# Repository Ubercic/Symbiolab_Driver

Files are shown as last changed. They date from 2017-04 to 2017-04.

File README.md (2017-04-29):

# Symbiolab Driver

## Overwiev 

Symbiolab driver was developed by institute IRNAS Rače for symbiolab biolaboratory. Its goal is to be used in as much as possible DIY laboratory equipment created for symbiolab's professional use in their research. A full list of planned DIY equipment can be found [here](https://github.com/symbiolab/bio-labware/blob/master/010_general_preparation.md). To achieve the most diverse use for the driver, we decidet to use a modular design, the most common components(display, encoder..) will be included in the driver, where as the design specific components(relay, ESC) are to be on a separate module.

## Table of contents

* Overwiev
* Table of contents
* Design specification
* Power supply config
* Board layout
* Pinout definition
* Testing
* Schemetics
* Featured installments

## Design specification

* [Nodemcu](http://nodemcu.com/index_en.html)
* Incremental encoder
* [I2C OLED display](https://www.adafruit.com/product/326)
* Motor driver [DRV8825](https://www.pololu.com/product/2133)
* Analog in pins for sensor readings
* 12V power supply
* mount screws

## Power supply config

Most of the desired elements controled with the driver work on 12 volts, to bring down the voltage to the required 5V in the Vin pin for the nodemcu we use a TLV1117 voltege regulator. Avidional voltage ripple tantal capacitors are wired before and after the regulator. to switch the nodemcu on and off, we added a power switch on the 12V line before the TLV1117. The nodemcu voltage level is 3V, but it takes 5V input.

## Board layout 

The PCB is designed to be montued as a faceplate on the lab equippment. Therefore most of the components are on the back ob the board. On the front there are the OLED display and incremental encoder, for the user control. All of the nodemcu pins are arranged in a raspberry pinout, this enables the use of raspberry shields.
The only analog pin on the nodemcu is separate with the 3v3 and GND pins next to it.

## Pinout definiton

Pionut definition

## Testing

## Schematics

The schematic and PCB design were crated with the free CAD software KiCAD.

## Featured installments

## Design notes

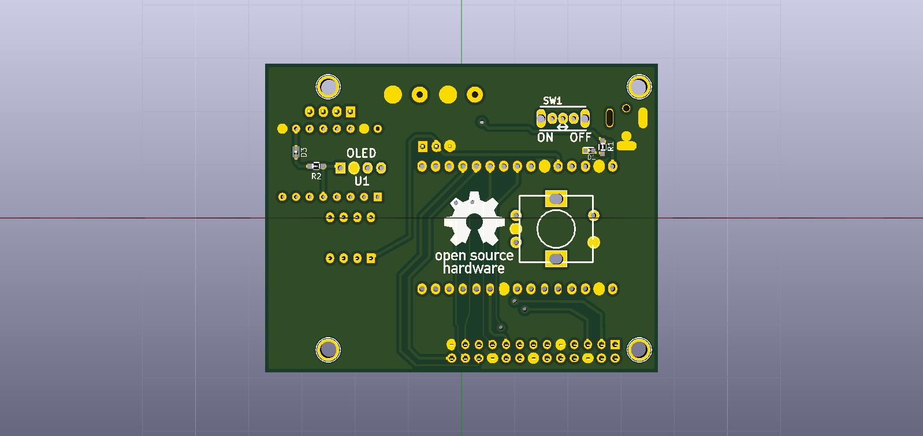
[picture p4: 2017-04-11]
KiCAD/IRNAS_Biolab_driver/Gerbers/IRNAS_BIOLAB_DRIVER_FRONT.jpg

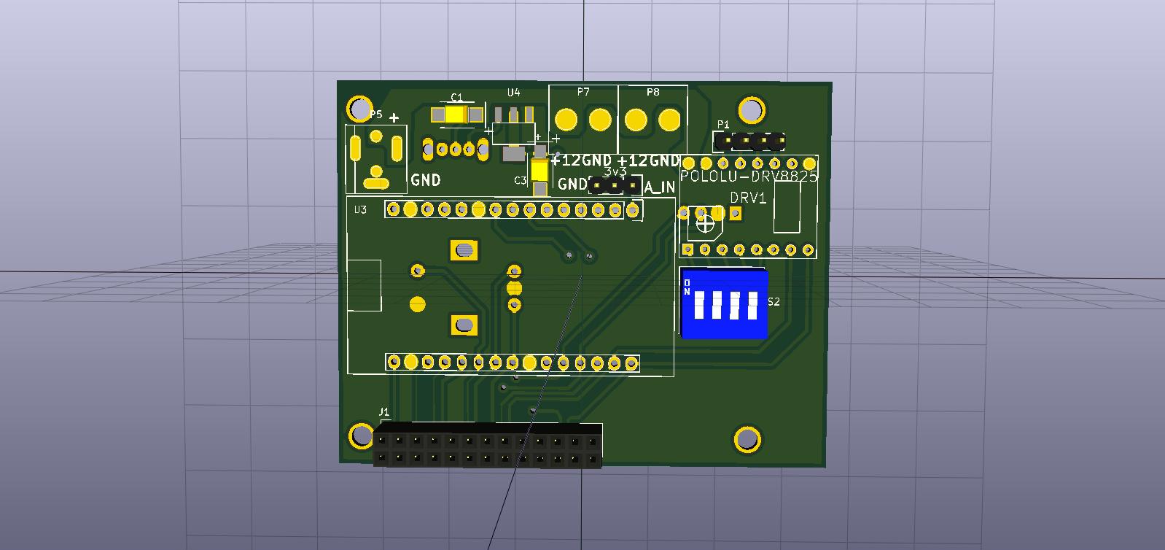
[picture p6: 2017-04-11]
KiCAD/IRNAS_Biolab_driver/Gerbers/IRNAS_BIOLAB_DRIVER_BACK.jpg

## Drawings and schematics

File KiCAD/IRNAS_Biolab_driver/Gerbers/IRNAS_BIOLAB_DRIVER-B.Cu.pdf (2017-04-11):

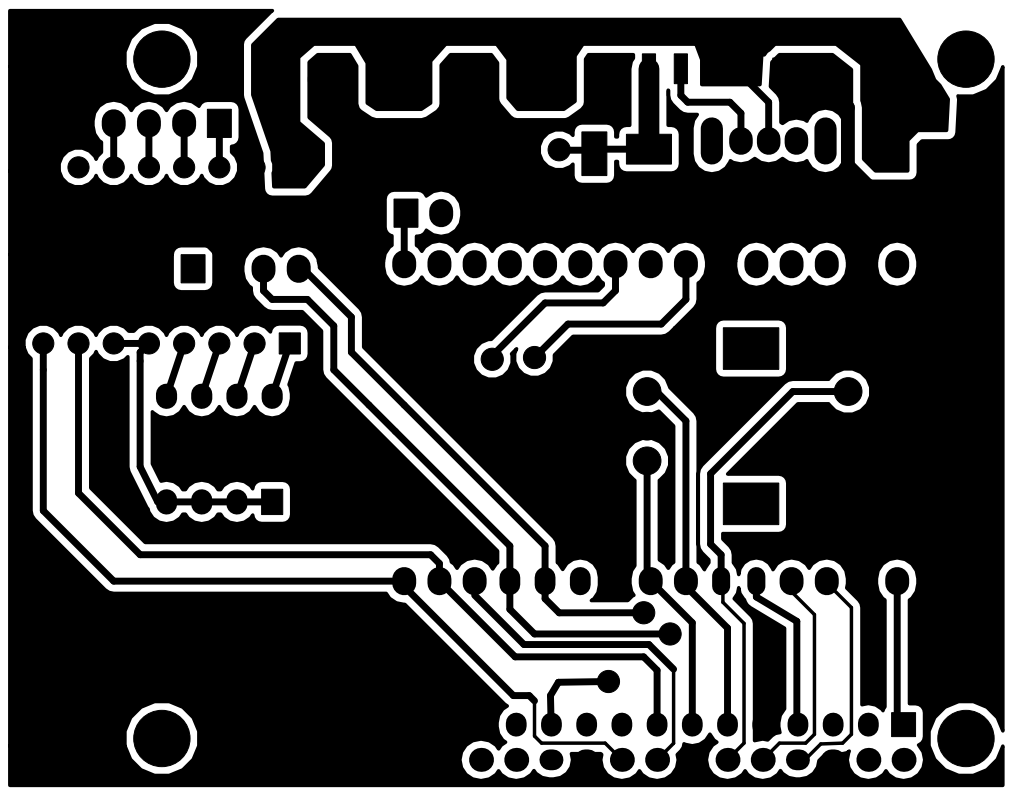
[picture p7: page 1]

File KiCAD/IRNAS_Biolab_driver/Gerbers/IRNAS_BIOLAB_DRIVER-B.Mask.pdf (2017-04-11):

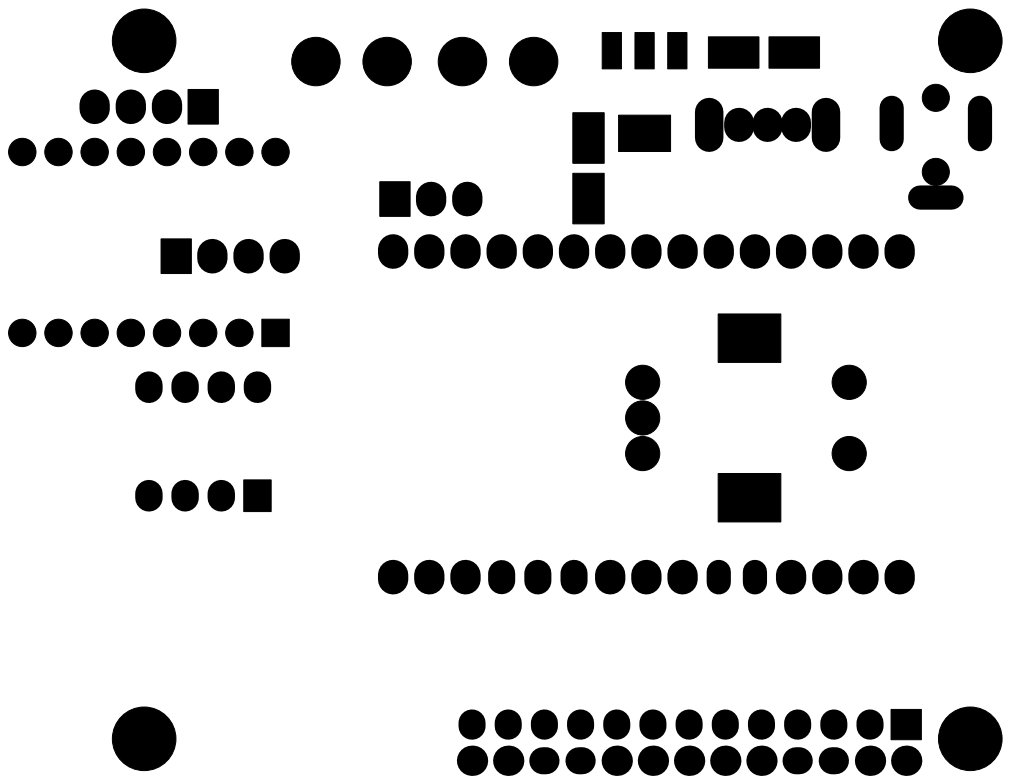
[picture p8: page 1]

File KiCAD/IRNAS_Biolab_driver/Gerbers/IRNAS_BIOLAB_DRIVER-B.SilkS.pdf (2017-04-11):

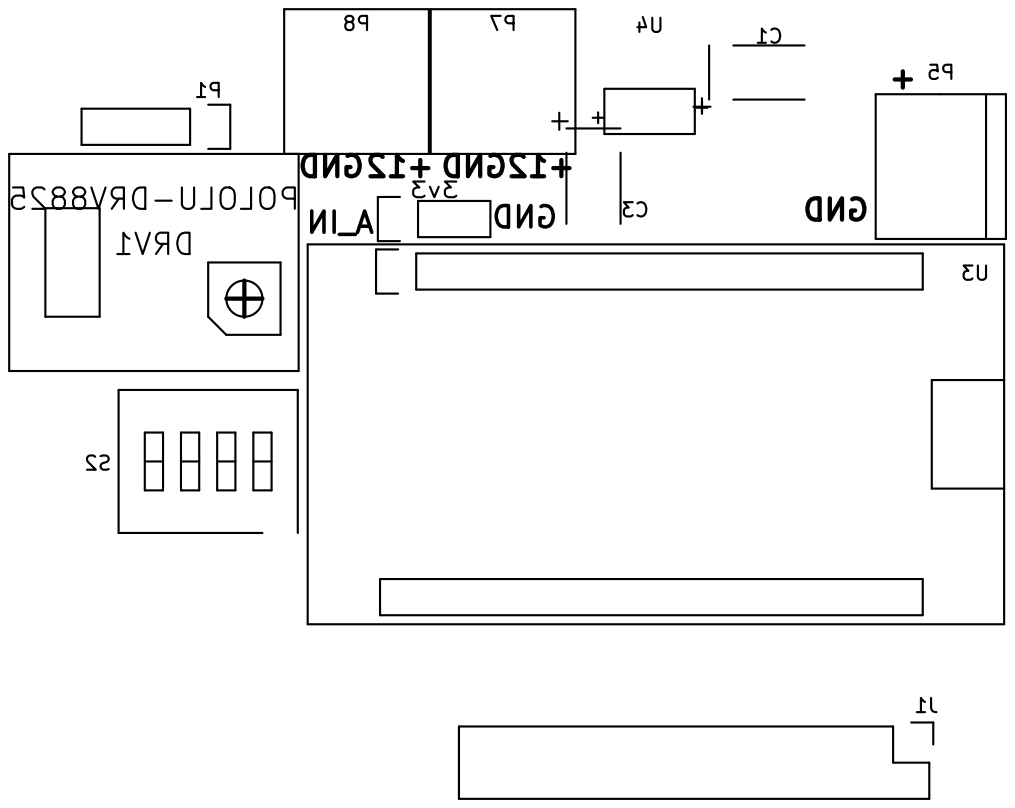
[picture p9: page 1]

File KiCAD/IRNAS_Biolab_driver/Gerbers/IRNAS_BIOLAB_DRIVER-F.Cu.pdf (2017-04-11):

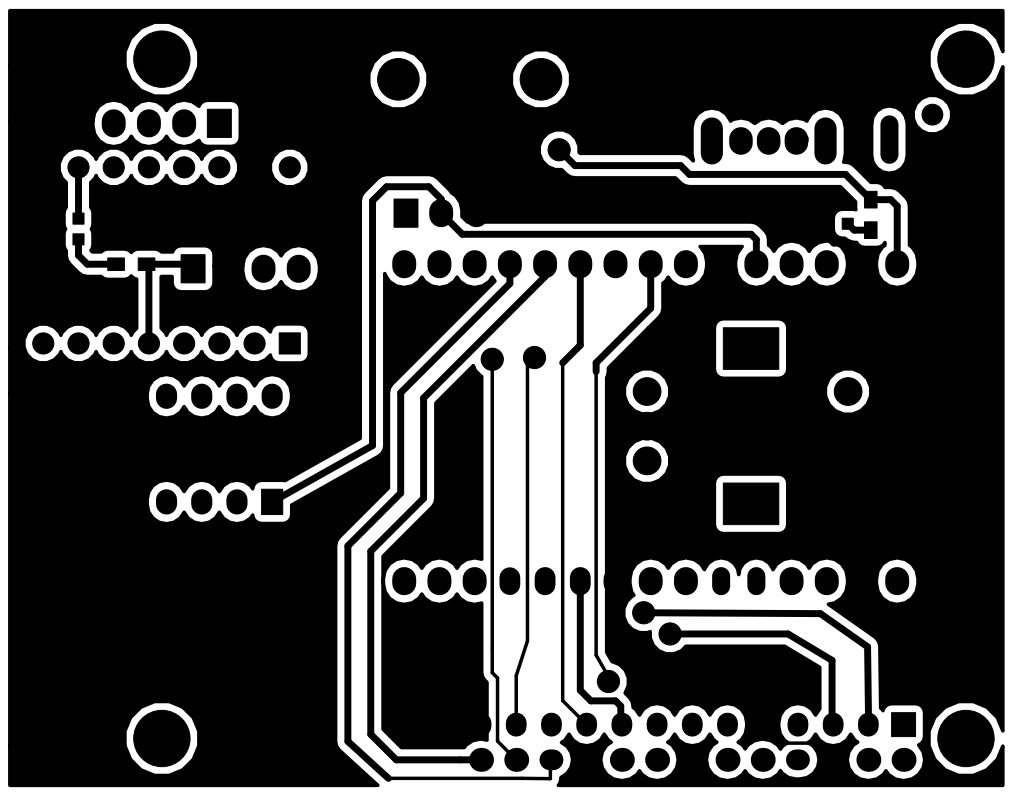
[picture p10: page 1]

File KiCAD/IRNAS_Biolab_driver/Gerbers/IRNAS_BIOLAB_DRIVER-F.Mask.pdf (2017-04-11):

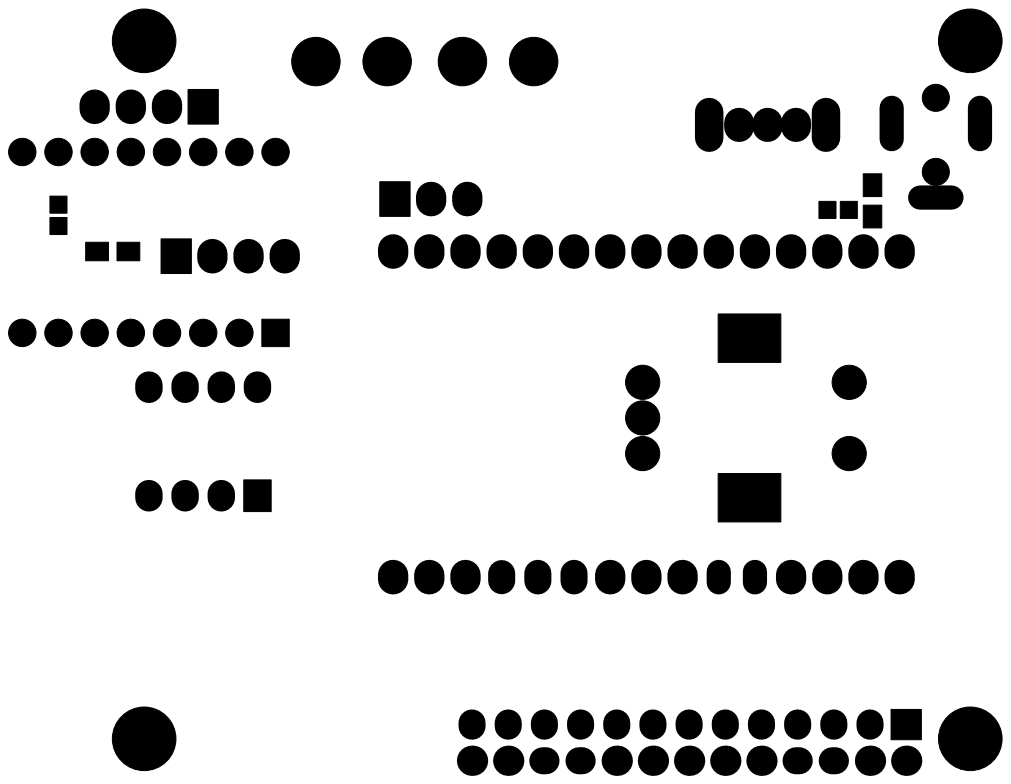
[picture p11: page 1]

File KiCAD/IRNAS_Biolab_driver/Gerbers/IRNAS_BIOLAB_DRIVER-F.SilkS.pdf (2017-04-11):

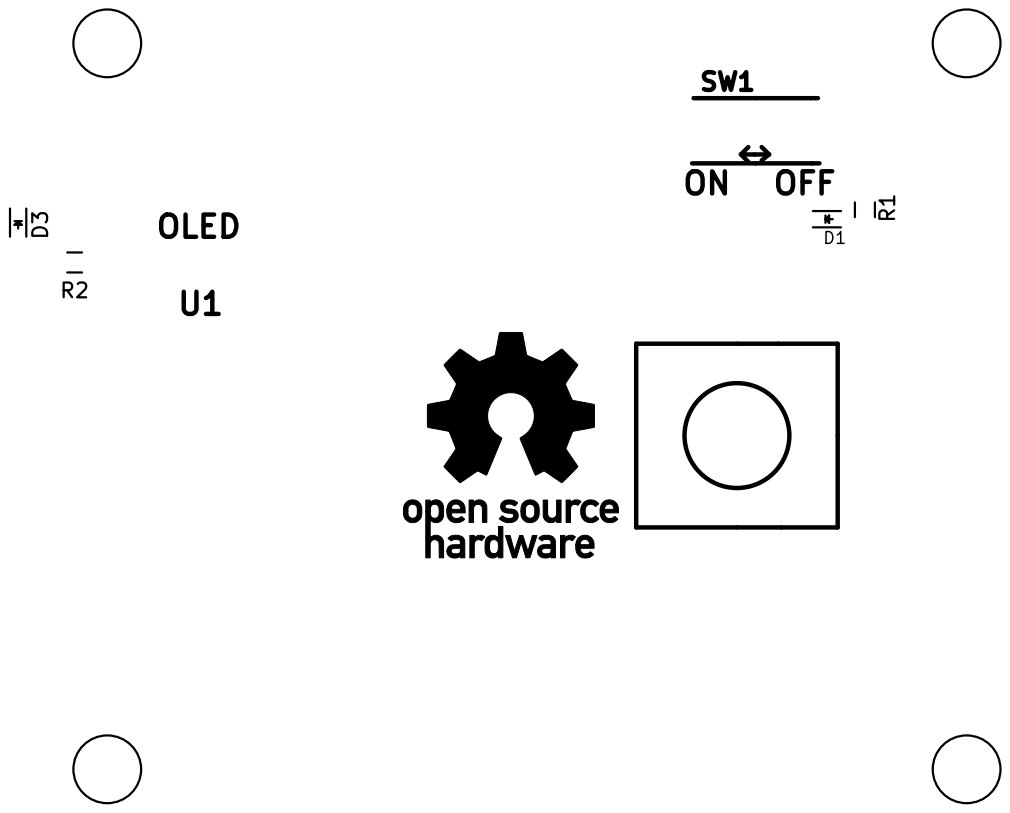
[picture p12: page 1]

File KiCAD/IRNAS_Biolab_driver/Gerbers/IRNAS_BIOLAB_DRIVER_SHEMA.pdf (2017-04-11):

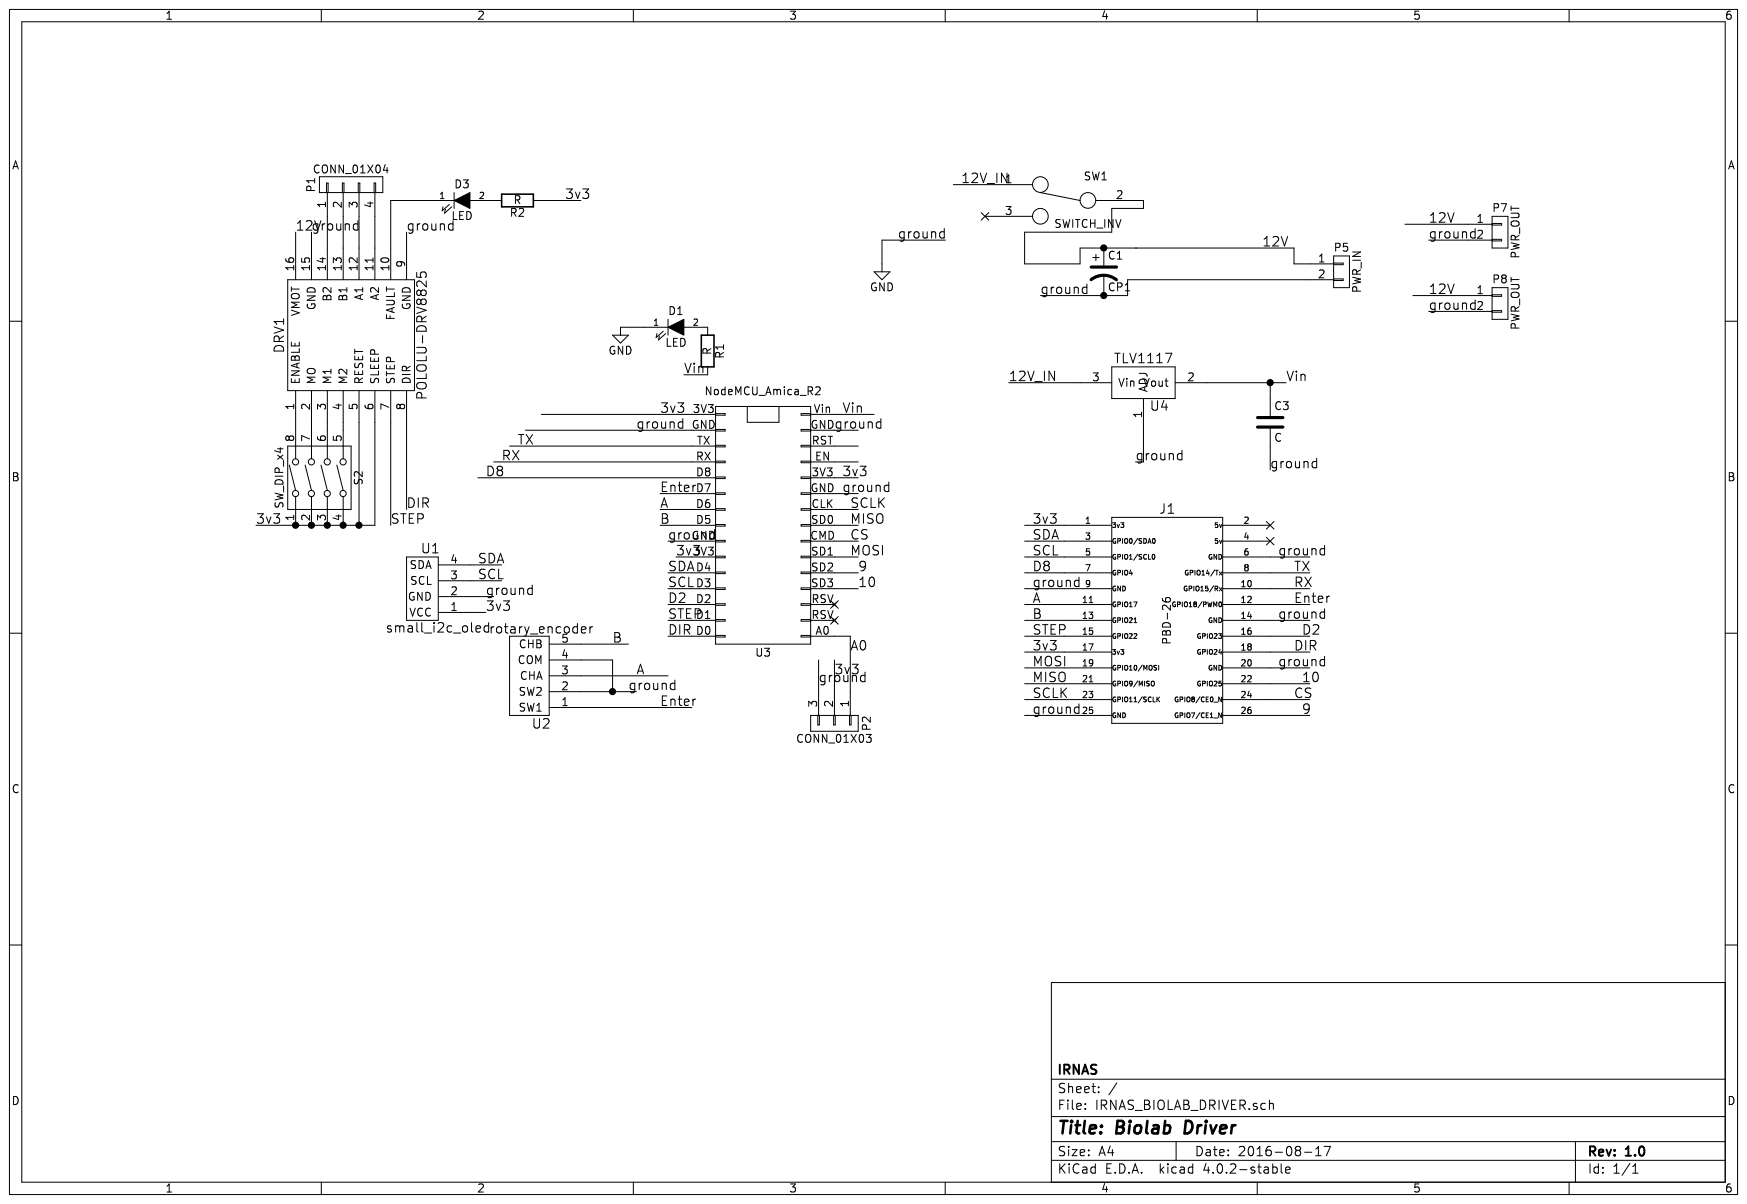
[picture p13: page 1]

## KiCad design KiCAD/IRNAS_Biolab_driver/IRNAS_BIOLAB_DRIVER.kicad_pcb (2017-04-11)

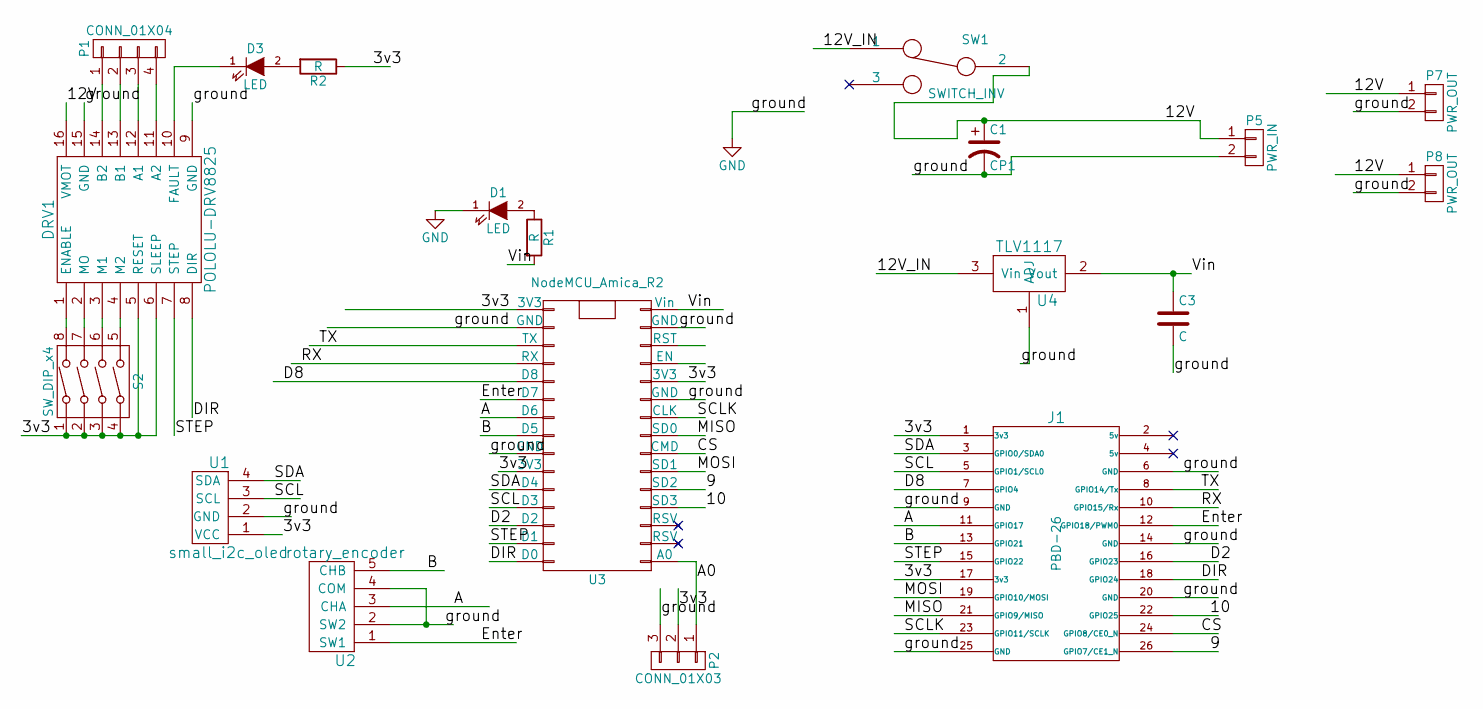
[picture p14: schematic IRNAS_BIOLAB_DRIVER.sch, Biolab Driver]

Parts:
C1: CP1; TantalC_SizeB_EIA-3528_HandSoldering
C3: C; TantalC_SizeB_EIA-3528_HandSoldering
D1, D3: LED; LED_0603
DRV1: POLOLU-DRV8825
J1: PBD-26; Socket_Strip_Straight_2x13
P1: CONN_01X04; Pin_Header_Straight_1x04
P2: CONN_01X03; Pin_Header_Straight_1x03
P5: PWR_IN; Power_universal
P7, P8: PWR_OUT; Terminal_block_5mm
R1, R2: R; R_0603_HandSoldering
S2: SW_DIP_x4; SW_DIP_x4_Slide
SW1: SWITCH_INV; OS102011MA1QN1_slide_switch
U1: small_i2c_oled; Small_I2C_OLED
U2: rotary_encoder; rotary_enc_bourns_EC12R-4215F-S0024
U3: NodeMCU_Amica_R2
U4: TLV1117

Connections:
/3v3: DRV1.5 (RESET), DRV1.6 (SLEEP), J1.1 (3v3), J1.17 (3v3), P2.2, R2.1, S2.1, S2.2, S2.3, S2.4, U1.1 (VCC), U3.11 (3V3), U3.16 (3V3), U3.25 (3V3)
/9: J1.26 (GPIO7/CE1_N), U3.5 (SD2)
/10: J1.22 (GPIO25), U3.4 (SD3)
/12V: C1.1, DRV1.16 (VMOT), P5.1, P7.1, P8.1, SW1.2
/12V_IN: SW1.1, U4.3 (Vin)
/A: J1.11 (GPIO17), U2.3 (CHA), U3.22 (D6)
/A0: P2.1, U3.1 (A0)
/B: J1.13 (GPIO21), U2.5 (CHB), U3.23 (D5)
/CS: J1.24 (GPIO8/CE0_N), U3.7 (CMD)
/D2: J1.16 (GPIO23), U3.28 (D2)
/D8: J1.7 (GPIO4), U3.20 (D8)
/DIR: DRV1.8 (DIR), J1.18 (GPIO24), U3.30 (D0)
/Enter: J1.12 (GPIO18/PWM0), U2.1 (SW1), U3.21 (D7)
/MISO: J1.21 (GPIO9/MISO), U3.8 (SD0)
/MOSI: J1.19 (GPIO10/MOSI), U3.6 (SD1)
/RX: J1.10 (GPIO15/Rx), U3.19 (RX)
/SCL: J1.5 (GPIO1/SCL0), U1.3 (SCL), U3.27 (D3)
/SCLK: J1.23 (GPIO11/SCLK), U3.9 (CLK)
/SDA: J1.3 (GPIO0/SDA0), U1.4 (SDA), U3.26 (D4)
/STEP: DRV1.7 (STEP), J1.15 (GPIO22), U3.29 (D1)
/TX: J1.8 (GPIO14/Tx), U3.18 (TX)
/Vin: C3.1, R1.2, U3.15 (Vin), U4.2 (Vout)
GND: C1.2, C3.2, D1.1 (K), DRV1.9 (GND), DRV1.15 (GND), J1.6 (GND), J1.9 (GND), J1.14 (GND), J1.20 (GND), J1.25 (GND), P2.3, P5.2, P7.2, P8.2, U1.2 (GND), U2.2 (SW2), U2.4 (COM), U3.10 (GND), U3.14 (GND), U3.17 (GND), U3.24 (GND), U4.1 (ADJ)
unnamed: D1.2 (A), R1.1
unnamed: D3.1 (K), DRV1.10 (FAULT)
unnamed: D3.2 (A), R2.2
unnamed: DRV1.1 (ENABLE), S2.8
unnamed: DRV1.2 (MO), S2.7
unnamed: DRV1.3 (M1), S2.6
unnamed: DRV1.4 (M2), S2.5
unnamed: DRV1.11 (A2), P1.4
unnamed: DRV1.12 (A1), P1.3
unnamed: DRV1.13 (B1), P1.2
unnamed: DRV1.14 (B2), P1.1

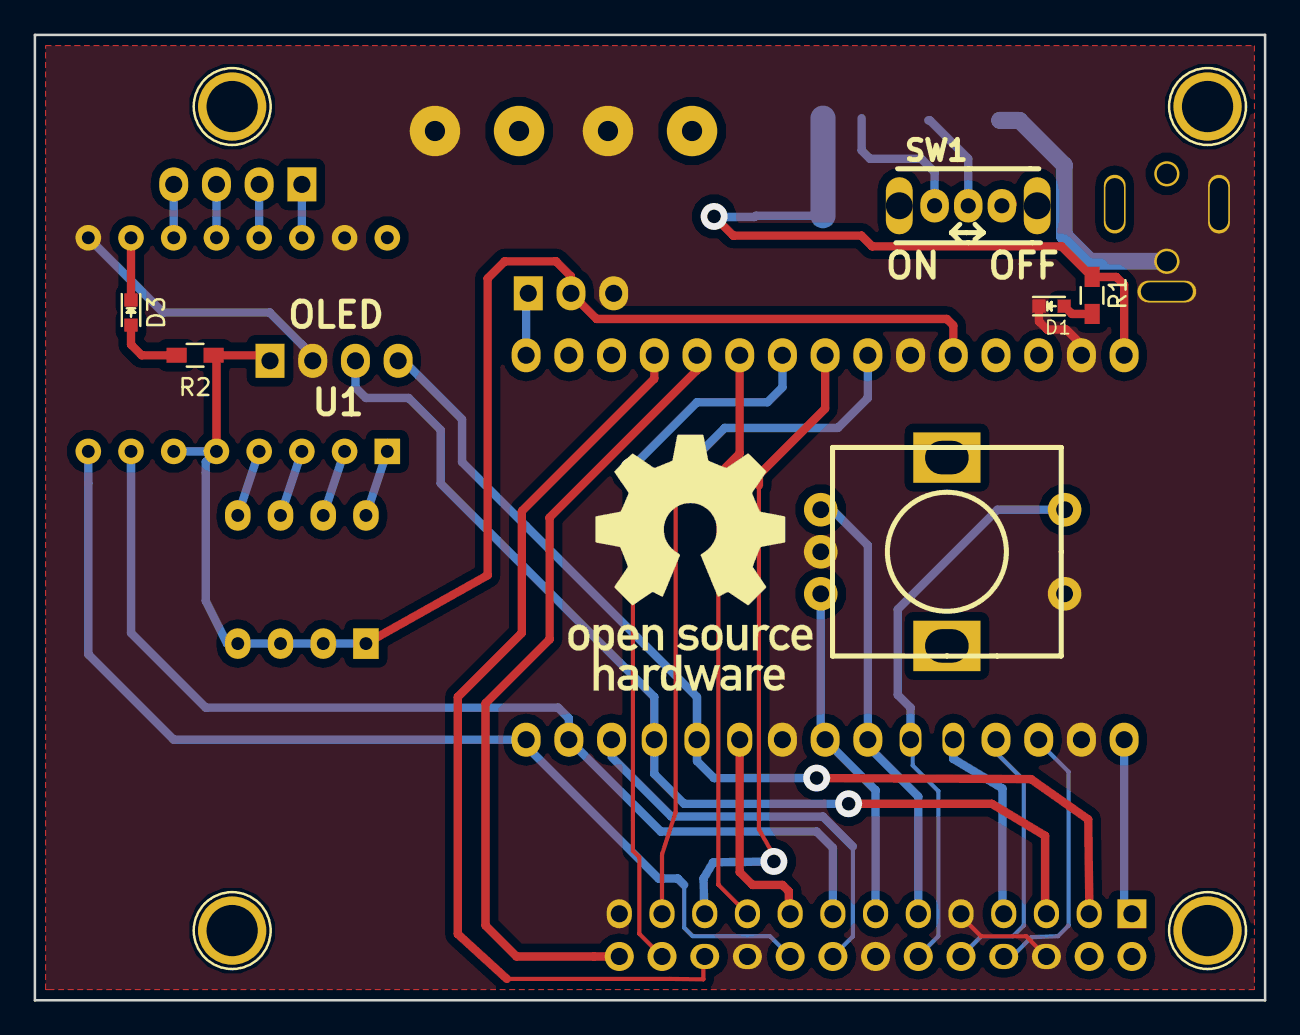
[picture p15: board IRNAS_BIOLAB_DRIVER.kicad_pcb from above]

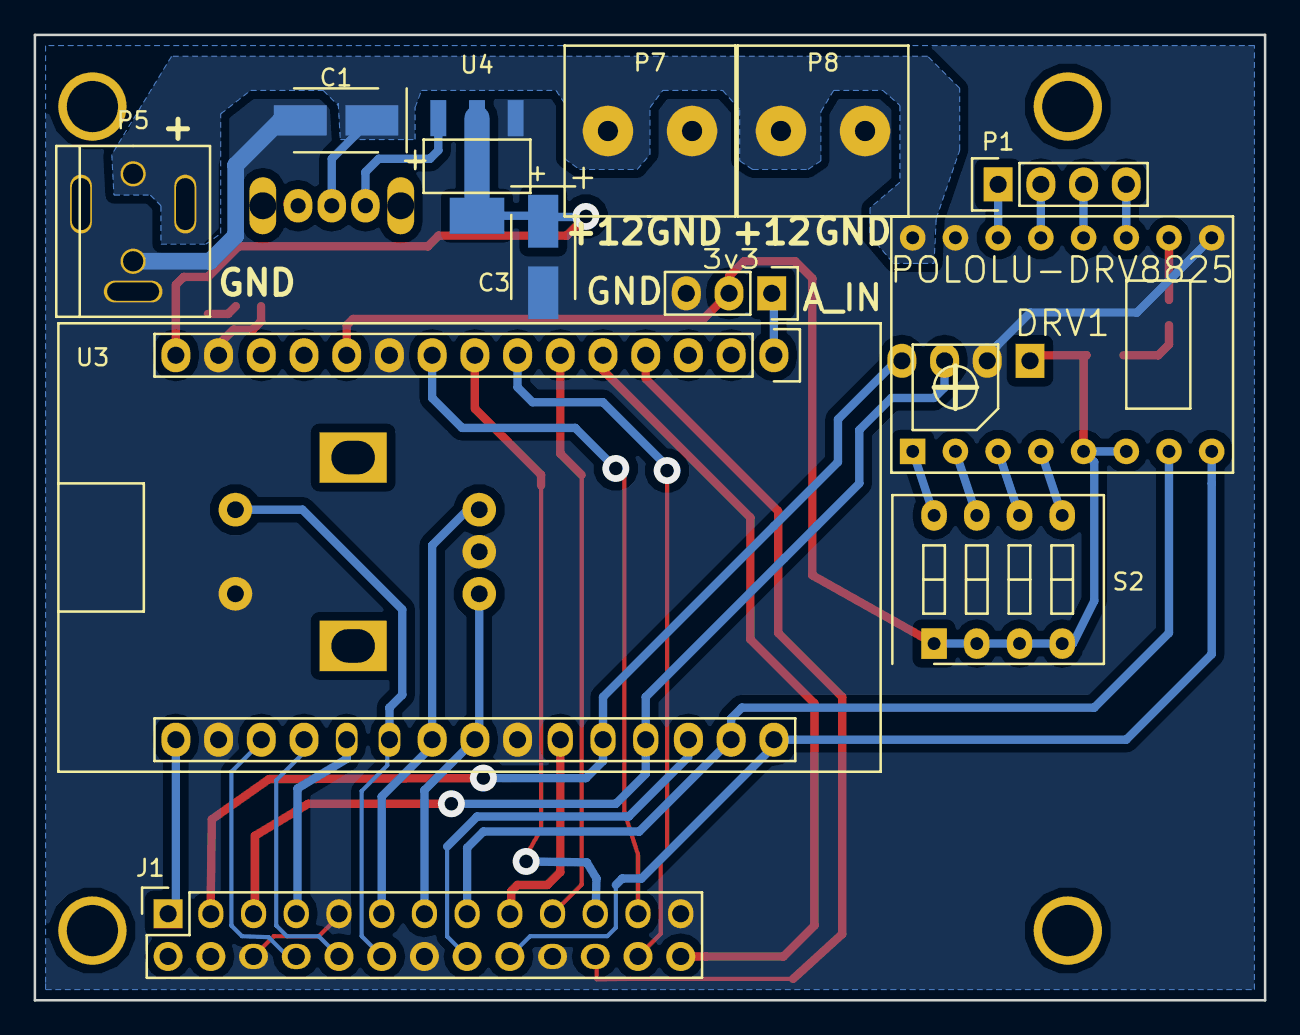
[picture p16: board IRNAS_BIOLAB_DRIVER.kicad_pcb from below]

Board: 2 copper layers, 73.2 x 57.4 mm, 19 parts (12 on the bottom side), 34 nets.

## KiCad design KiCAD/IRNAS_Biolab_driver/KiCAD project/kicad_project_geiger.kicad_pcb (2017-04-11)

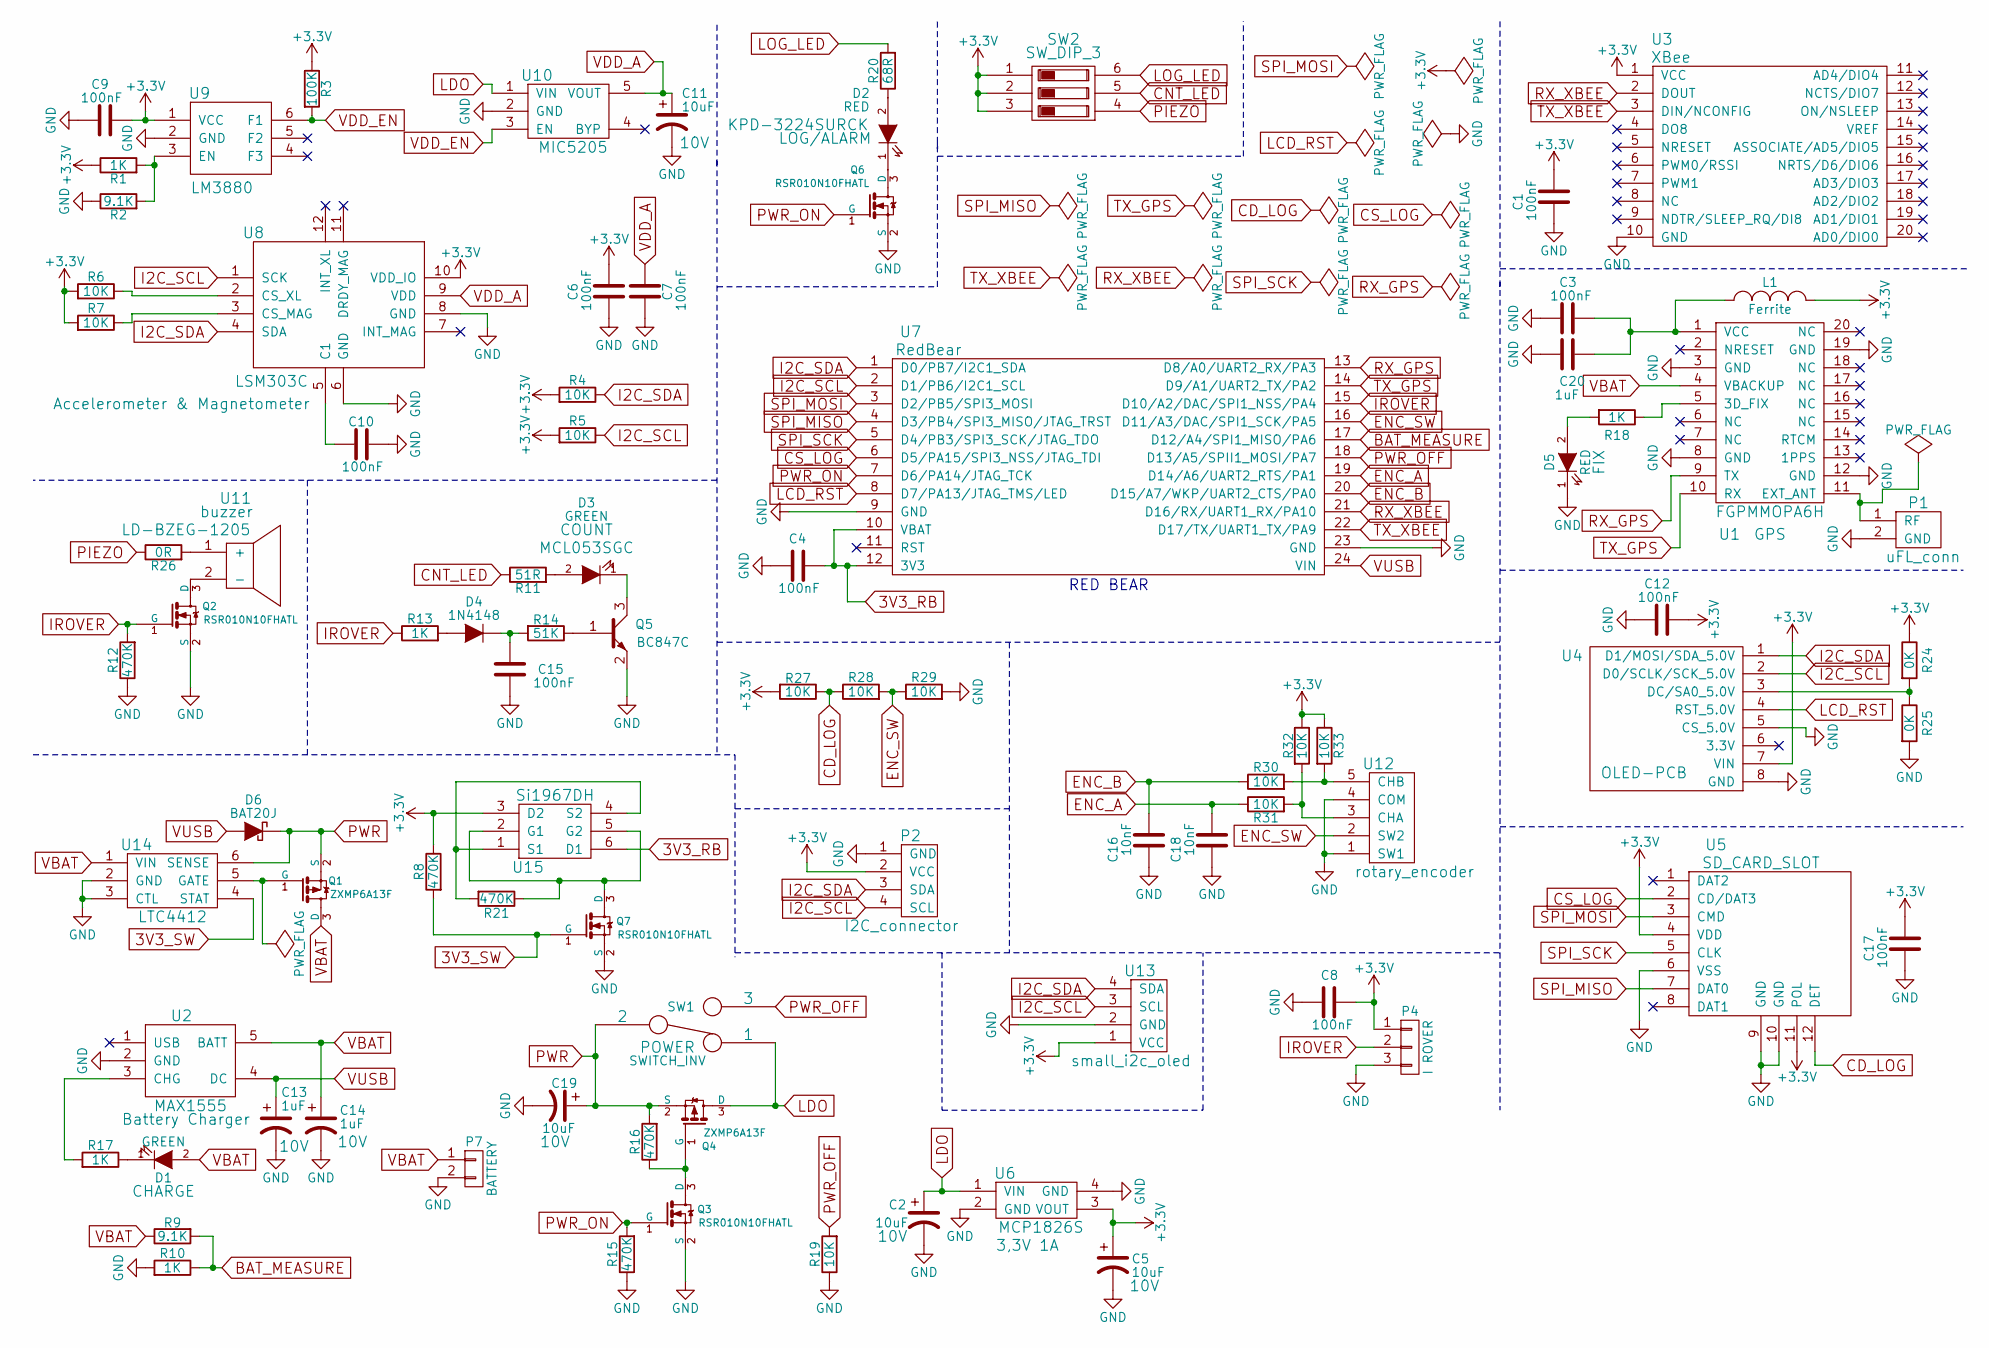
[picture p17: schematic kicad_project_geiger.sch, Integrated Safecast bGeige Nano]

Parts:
C1, C3, C4, C6, C7, C8, C9, C10, C12, C15, C17: 100nF; R_0603_HandSoldering
C2, C5, C11, C19: 10uF; TantalC_SizeB_EIA-3528_HandSoldering; Voltage 10V
C13, C14: 1uF; TantalC_SizeB_EIA-3528_HandSoldering; Voltage 10V
C16, C18: 10nF; R_0603_HandSoldering
C20: 1uF; R_0603_HandSoldering
D1: GREEN; LED_0603_HandSoldering
D2: RED; KPD-3224SURCK
D3: GREEN; MCL053SGC
D4: 1N4148; SOD-323
D5: RED; LED_0603_HandSoldering
D6: BAT20J; SOD-323
L1: Ferrite; R_0603_HandSoldering
P1: uFL_conn; U.FL-R-SMT
P2: I2C_connector; DIP_Grove_4P-2_0
P4: I ROVER; B3B-PH-SM4-TB_IROVER_CONNECTOR
P7: BATTERY; B2B-PH-SM4-TB_Battery_Connector
Q1, Q4: ZXMP6A13F; SOT-23
Q2, Q3, Q6, Q7: RSR010N10FHATL; SOT-23
Q5: BC847C; SOT-23
R1, R10, R13, R17, R18: 1K; R_0603_HandSoldering
R2, R9: 9.1K; R_0603_HandSoldering
R3: 100K; R_0603_HandSoldering
R4, R5, R6, R7, R19, R27, R28, R29, R30, R31, R32, R33: 10K; R_0603_HandSoldering
R8, R12, R15, R16, R21: 470K; R_0603_HandSoldering
R11: 51R; R_0603_HandSoldering
R14: 51K; R_0603_HandSoldering
R20: 68R; R_0603_HandSoldering
R24, R25: 0K; R_0603_HandSoldering
R26: 0R; R_0603_HandSoldering
SW1: SWITCH_INV; OS102011MA1QN1_slide_switch
SW2: SW_DIP_3; OMRON_ELECTRONIC_COMPONENTS_A6S-3102-H_DIP_Switch
U1: FGPMMOPA6H; FGPMMOPA6H_GPS
U2: MAX1555; SOT-23-5
U3: XBee; xbee
U4: OLED-PCB; Adafruit-1_3inch-128x64-Mono-OLED-PCB-master
U5: SD_CARD_SLOT; MOLEX_47309-2651_CONNECTOR_MICRO_SD
U6: MCP1826S; MCP1826S_SOT223
U7: RedBear
U8: LSM303C
U9: LM3880
U10: MIC5205
U11: buzzer; LD-BZEG-1205
U12: rotary_encoder; rotary_enc_bourns_EC12R-4215F-S0024
U13: small_i2c_oled; Small_I2C_OLED
U14: LTC4412
U15: Si1967DH

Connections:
3V3_RB: C4.2, U7.10 (VBAT), U7.12 (3V3), U15.6 (D1)
3V3_SW: Q7.1 (G), R8.2, U14.4 (STAT)
+3V3: C1.2, C5.1, C6.2, C8.1, C9.2, C12.2, C17.2, L1.2, P2.2 (VCC), P4.1, R1.1, R3.1, R4.2, R5.2, R6.2, R7.2, R8.1, R24.1, R27.2, R32.1, R33.1, SW2.1, SW2.2, SW2.3, U3.1 (VCC), U4.7 (VIN), U5.4 (VDD), U5.11 (POL), U6.3 (VOUT), U8.10 (VDD_IO), U9.1 (VCC), U13.1 (VCC), U15.3 (D2)
BAT_MEASURE: R9.2, R10.1, U7.17 (D12/A4/SPI1_MISO/PA6)
CD_LOG: R27.1, R28.1, U5.12 (DET)
CNT_LED: R11.1, SW2.5
CS_LOG: U5.2 (CD/DAT3), U7.6 (D5/PA15/SPI3_NSS/JTAG_TDI)
ENC_A: C18.2, R31.1, U7.19 (D14/A6/UART2_RTS/PA1)
ENC_B: C16.2, R30.1, U7.20 (D15/A7/WKP/UART2_CTS/PA0)
ENC_SW: R28.2, R29.1, U7.16 (D11/A3/DAC/SPI1_SCK/PA5), U12.2 (SW2)
GND: C1.1, C2.2, C3.2, C4.1, C5.2, C6.1, C7.1, C8.2, C9.1, C10.2, C11.2, C12.1, C13.2, C14.2, C15.2, C16.1, C17.1, C18.1, C19.2, C20.2, D5.1 (K), P1.2 (GND), P2.1 (GND), P4.3, P7.2, Q2.2 (S), Q3.2 (S), Q5.2 (E), Q6.2 (S), Q7.2 (S), R2.1, R10.2, R12.1, R15.1, R19.1, R25.2, R29.2, U1.3 (GND), U1.8 (GND), U1.12 (GND), U1.19 (GND), U2.2 (GND), U3.10 (GND), U4.5 (CS_5.0V), U4.8 (GND), U5.6 (VSS), U5.9 (GND), U5.10 (GND), U6.2 (GND), U6.4 (GND), U7.9 (GND), U7.23 (GND), U8.6 (GND), U8.8 (GND), U9.2 (GND), U10.2 (GND), U12.1 (SW1), U12.4 (COM), U13.2 (GND), U14.2 (GND), U14.3 (CTL)
I2C_SCL: P2.4 (SCL), R5.1, U4.2 (D0/SCLK/SCK_5.0V), U7.2 (D1/PB6/I2C1_SCL), U8.1 (SCK), U13.3 (SCL)
I2C_SDA: P2.3 (SDA), R4.1, U4.1 (D1/MOSI/SDA_5.0V), U7.1 (D0/PB7/I2C1_SDA), U8.4 (SDA), U13.4 (SDA)
IROVER: P4.2, Q2.1 (G), R12.2, R13.1, U7.15 (D10/A2/DAC/SPI1_NSS/PA4)
LCD_RST: U4.4 (RST_5.0V), U7.8 (D7/PA13/JTAG_TMS/LED)
LDO: C2.1, Q4.3 (D), SW1.1, U6.1 (VIN), U10.1 (VIN)
LOG_LED: R20.2, SW2.6
unnamed: C10.1, U8.5 (C1)
unnamed: C15.1, D4.1 (K), R14.2
unnamed: C3.1, C20.1, L1.1, U1.1 (VCC)
unnamed: D1.1 (K), R17.1
unnamed: D2.1 (K), Q6.3 (D)
unnamed: D2.2 (A), R20.1
unnamed: D3.1 (K), Q5.3 (C)
unnamed: D3.2 (A), R11.2
unnamed: D4.2 (A), R13.2
unnamed: D5.2 (A), R18.2
unnamed: P1.1 (RF), U1.11 (EXT_ANT)
unnamed: Q1.1 (G), U14.5 (GATE)
unnamed: Q2.3 (D), U11.2 (-)
unnamed: Q3.3 (D), Q4.1 (G), R16.1
unnamed: Q5.1 (B), R14.1
unnamed: Q7.3 (D), R21.1, U15.2 (G1), U15.5 (G2)
unnamed: R1.2, R2.2, U9.3 (EN)
unnamed: R6.1, U8.2 (CS_XL)
unnamed: R7.1, U8.3 (CS_MAG)
unnamed: R17.2, U2.3 (CHG)
unnamed: R18.1, U1.5 (3D_FIX)
unnamed: R21.2, U15.1 (S1), U15.4 (S2)
unnamed: R24.2, R25.1, U4.3 (DC/SA0_5.0V)
unnamed: R26.2, U11.1 (+)
unnamed: R30.2, R33.2, U12.5 (CHB)
unnamed: R31.2, R32.2, U12.3 (CHA)
PIEZO: R26.1, SW2.4
PWR: C19.1, D6.1 (K), Q1.2 (S), Q4.2 (S), R16.2, SW1.2, U14.6 (SENSE)
PWR_OFF: R19.2, SW1.3, U7.18 (D13/A5/SPII1_MOSI/PA7)
PWR_ON: Q3.1 (G), Q6.1 (G), R15.2, U7.7 (D6/PA14/JTAG_TCK)
RX_GPS: U1.9 (TX), U7.13 (D8/A0/UART2_RX/PA3)
RX_XBEE: U3.2 (DOUT), U7.21 (D16/RX/UART1_RX/PA10)
SPI_MISO: U5.7 (DAT0), U7.4 (D3/PB4/SPI3_MISO/JTAG_TRST)
SPI_MOSI: U5.3 (CMD), U7.3 (D2/PB5/SPI3_MOSI)
SPI_SCK: U5.5 (CLK~), U7.5 (D4/PB3/SPI3_SCK/JTAG_TDO)
TX_GPS: U1.10 (RX), U7.14 (D9/A1/UART2_TX/PA2)
TX_XBEE: U3.3 (DIN/NCONFIG), U7.22 (D17/TX/UART1_TX/PA9)
VBAT: C14.1, D1.2 (A), P7.1, Q1.3 (D), R9.1, U1.4 (VBACKUP), U2.5 (BATT), U14.1 (VIN)
VDD_A: C7.2, C11.1, U8.9 (VDD), U10.5 (VOUT)
VDD_EN: R3.2, U9.6 (F1), U10.3 (EN)
VUSB: C13.1, D6.2 (A), U2.4 (DC), U7.24 (VIN)

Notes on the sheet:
RED BEAR

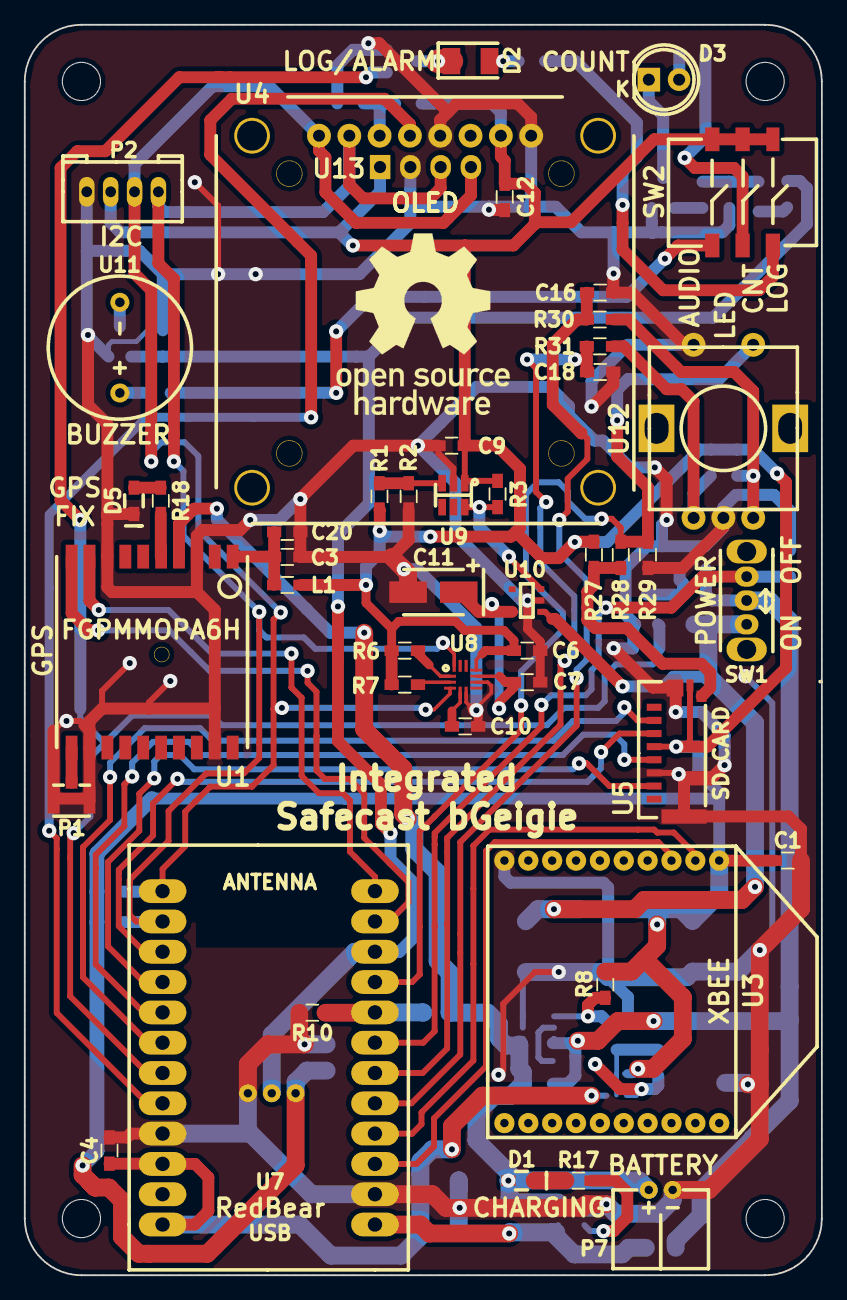
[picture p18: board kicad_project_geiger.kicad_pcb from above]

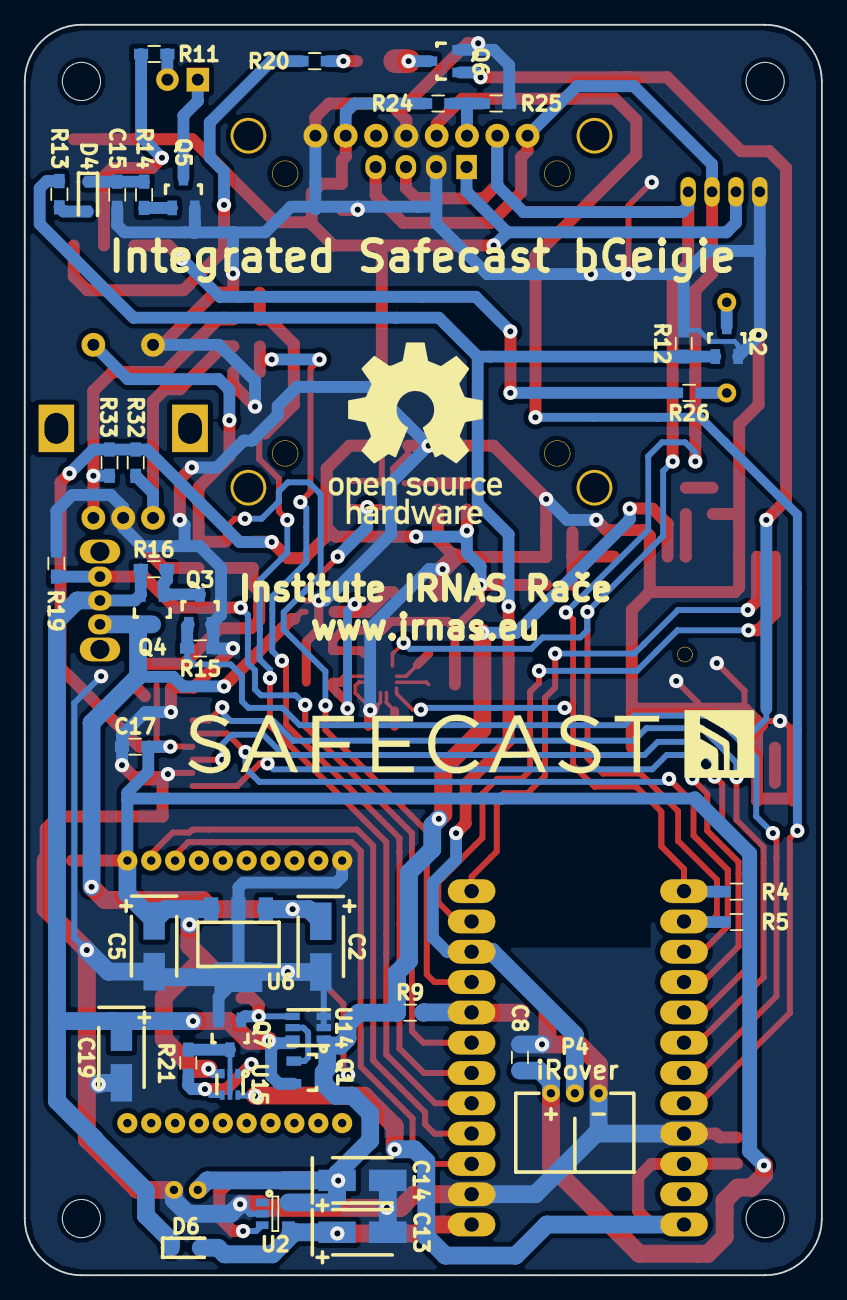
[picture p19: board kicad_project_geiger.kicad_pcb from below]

Board: 2 copper layers, 66.8 x 104.8 mm, 86 parts (39 on the bottom side), 58 nets.

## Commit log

2017-04-11 added first files
    [IRNAS_BIOLAB_DRIVER-B.Cu.gbl, IRNAS_BIOLAB_DRIVER-B.Mask.gbs, IRNAS_BIOLAB_DRIVER-B.SilkS.gbo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]
2017-04-29 updated readme and added pinout png
    removed xls too
    [Symbiolab_driver_pinout.xlsx]
